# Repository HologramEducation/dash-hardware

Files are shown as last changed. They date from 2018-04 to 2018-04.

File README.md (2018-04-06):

# Hologram Dash Hardware Repository

The Hologram Dash is an Open-Sourced Cellular MCU Developer Board utilizing the [ublox SARA](https://www.u-blox.com/en/product-search/field_product_form/sara-111) family of modems, [ARM Cortex-M0+](https://www.mouser.com/ProductDetail/NXP-Freescale/MKL17Z256VFM4/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), and an [ARM Cortex-M4](https://www.mouser.com/productdetail/nxp-freescale/mk22fn1m0avlh12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). 

Certified by the Open Source Hardware Association - [Certificate US000082](http://certificate.oshwa.org/certification-directory/).

We're excited to see what you'll build with these designs. If you require support for integrating these designs into your project, you can reach out to Hologram Solutions Engineering at sales@hologram.io to learn about Hologram design review services or hear about our engineering design partners.

### Additional Dash Information

 - [Dash Product Page](https://hologram.io/dash/)
 - [Dash Datasheet](https://hologram.io/docs/reference/dash/datasheet/)
 - [Pre v1.2 Dash Repo](https://github.com/hologram-io/hologram-hardware)

### Additional Freescale Documentation

 - [Freescale ARM Cortex-M0+ MKL17Z256VFM4 Datasheet](https://www.mouser.com/ds/2/302/KL17P64M48SF6-1126486.pdf)
 - [Freescale ARM Cortex-M4 MK22FN1M0AVLH12 Datasheet](https://www.mouser.com/ds/2/302/K22P64M120SF5V2-1126240.pdf)

### Additional ublox SARA Documentation

**2G/3G - U200 series**
 - [SARA-U2 System Integration Manual](https://www.u-blox.com/sites/default/files/SARA-G3-U2_SysIntegrManual_%28UBX-13000995%29_0.pdf)
 - [u-blox AT Commands Manual](https://www.u-blox.com/sites/default/files/u-blox-CEL_ATCommands_%28UBX-13002752%29.pdf)
 - [AT Command Examples for u-blox cellular modules](https://www.u-blox.com/sites/default/files/AT-CommandsExamples_AppNote_%28UBX-13001820%29.pdf)
 - [Multiplexer implementation in cellular modules](https://www.u-blox.com/sites/default/files/products/documents/MuxImplementation_ApplicationNote_%28UBX-13001887%29.pdf)
 
**LTE Cat M1/NB1 and EGPRS - R400/N400 series**

 - [SARA-R4 System Integration Manual](https://www.u-blox.com/sites/default/files/SARA-R4_SysIntegrManual_%28UBX-16029218%29.pdf)
 - [SARA-R4 AT Commands Manual](https://www.u-blox.com/sites/default/files/SARA-R4_ATCommands_%28UBX-17003787%29.pdf)

**Power-optimized NB-IoT - N200 series**

 - [SARA-N2 System Integration Manual](https://www.u-blox.com/sites/default/files/SARA-N2_SysIntegrManual_%28UBX-17005143%29.pdf)
 - [SARA-N2 AT Commands](https://www.u-blox.com/sites/default/files/SARA-N2_ATCommands_%28UBX-16014887%29.pdf)

### Additional Hologram Information

 - [BLOG Why We Open Source Hardware](https://hologram.io/open-sourcing-our-hardware/)
 - [Documentation](https://hologram.io/docs/)
 - [Forums](https://community.hologram.io/)

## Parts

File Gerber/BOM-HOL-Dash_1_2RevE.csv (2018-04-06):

Internal PN | LibRef | Quantity | Designator | Description | Footprint | Comment | MFG | MPN
CON-0006 | ANT-A-1JB | 1 | ANT_UFL | Amphenol | UFL | ANT-A-1JB | Amphenol | A-1JB
CON-0010 | BAT_TERM_TOP_ENTRY | 1 | J20 | Battery Connector JST-PH2 Top Entry | JST-PH-2-Top | BAT_TERM_TOP_ENTRY | JST | B2B-PH-SM4-TB(LF)(SN)
CAP-0004 | CAP0.1uF_0402 | 15 | C2, C3, C4, C6, C7, C8, C9, C12, C14, C15, C18, C24, C25, C26, C48 | CAPACITOR, 0.1 uF, 0402 | CAP0402 | 0.1 uF | MURATA | GRM155R61C104KA88D
CAP-0005 | CAP1uF_0402 | 3 | C16, C20, C49 | CAPACITOR, 1uF, 0402 | CAP0402 | 1uF | AVX | 04026D105KAT2A
CAP-0001 | CAP1uF_0603 | 1 | C1 | Capacitor, 1 uF, 0603 | CAP0603 | 1 uF | MURATA | GRM188R71C105KA12D
CAP-0002 | CAP2.2uF_0603 | 4 | C10, C11, C13, C28 | Capacitor, 2.2 uF, 0603 | CAP0603 | 2.2 uF | SAMSUNG | CL10A225MQ8NNNC
CAP-0016 | CAP10nF_0402 | 2 | C27, C39 | CAPACITOR, 10 nF, 0402 | CAP0402 | 10 nF | MURATA | GRM155R71C103KA01D
CAP-0007 | CAP10uF_0603 | 2 | C33, C34 | Capacitor, 10 uF, 0603 | CAP0603 | 10 uF | Murata | GRM188R60J106ME84D
CAP-0011 | CAP15pF_0402 | 1 | C46 | CAPACITOR, 15 pF, 0402 | CAP0402 | 15 pf | AVX/ELCO | 04025A150JAT2A
CAP-0008 | CAP22uF_0603 | 3 | C36, C37, C38 | Capacitor, 22 uF, 0603 | CAP0603 | 22 uF | MURATA | GRM188R60J226MEA0D
CAP-0010 | CAP47pf_0402 | 4 | C41, C42, C44, C45 | CAPACITOR, 47 pF, 0402 | CAP0402 | 47 pF | AVX | 04025A470JAT2A
CAP-0009 | CAP56pF_0402 | 1 | C40 | CAPACITOR, 56 pF, 0402 | CAP0402 | 56 pf | KEMET | C0402C560J5GACTU
CAP-0012 | CAP330uF_1210P | 1 | C47 | Capacitor, 330 uF, 1210, Polarized Tantalum | CAP1210POL | 330uF | AVX | F950J337MBAAQ2
XTL-0001 | CRYSTAL_16MHz | 1 | X1 | Crystal SMD, 16 MHz | CRYSTAL-SMD-2X1.6 | CRYSTAL_16MHz | AVX | CX2016DB16000D0WZRC1
XTL-0003 | CRYSTAL_32.768K_ABS05 | 2 | X2, X3 | 32.768kHz ±20ppm Crystal 12.5pF 90 kOhm -40°C ~ 85°C Surface Mount 2-SMD | CRYSTAL_ABS05 | 32.768 kHz | Abracon | ABS05-32.768KHZ-T
DIO-0004 | DIODE_0402_200mA | 1 | D8 | Schottky Barrier Diode, 200 mA, 30 V, 0402 package | DIODE_0402 | CDBQR0230L | Comchip | CDBQR0230L
DIO-0005 | DIODE_SOD123F_1A | 2 | U3, U4 | Schottky Barrier Diode, 1.5 A, 30 V, 0402 package | SODFL350X99-2N | CDBQR0230L | Toshiba Semiconductor and Storage | CRS08(TE85L,Q,M)
IND-0001 | FerriteBead_220ohm | 4 | L1, L2, L3, L7 | FerriteBead, 220ohm | RES0603 | FerriteBead_220ohm | Murata | BLM18AG121SN1D
IC-0009 | FREESCALE_MKL17Z256VFM4 | 1 | U6 | Microprocessor, Freescale, MKL17Z256VFM4 | QFN50P50 | FREESCALE_MKL17Z256VFM4 | FREESCALE | MKL17Z256VFM4
FUS-0001 | FUSE_0603 | 1 | F6 | Fuse, 3A, 0603 | RES0603 | 3A | Bourns | SF-0603S300-2
IND-0003 | INDUCTOR_1UH_XFL4020-102MEC | 1 | L5 | Inductor, 1 uH, Coilcraft | COILCRAFT_XFL4020 | 1uH | Coilcraft | XFL4020-102MEC
DIO-0002 | LED_0402_VLMW | 2 | D1, D7 | LED, Vishay White 0402 | LED_0402_VISHAY_VLMW | LED_0402_VLMW | VISHAY | VLMW1500-GS08
DIO-0006 | LED_RGB_1mm_sq | 1 | D2 | LED, Tri-color, RGB, 1mm sq | LED-RGB-1X1 | LED_RGB_1mm_sq | Rohm | SMLP34RGB2W3
IC-0003 | MAX1704X | 1 | U19 | MAX17043/MAX17044: Battery Fuel Guage (43 is 1cell, 44 is 2cell) | TDFN-8 | MAX1704X | Maxim | MAX17043G+U
IC-0012 | MICROCHIP_73871 | 1 | U1 | Stand-alone Load Sharing and LiPo Battery Charge management controller | QFN50P400X400X80_20_pin | MICROCHIP_73871 | MICROCHIP | MCP73871-2CCI/ML
IC-0008 | MK22FN1M0VLH12 | 1 | U5 | ARM® Cortex®-M4 Kinetis K20 Microcontroller IC 32-Bit 120MHz 1MB (1M x 8) FLASH 64-LQFP (10x10) | LQFP-64N | MK22FN1M0VLH12 | Freescale | MK22FN1M0AVLH12
IC-0002 | NCP177-D | 1 | U10 | IC Regulator, LDO 3.3V 0.5A, 4XDFN | XDFN-4 |  | On Semi | NCP177AMX330TCG
DIO-0009 | PESD_14V | 7 | D3, D4, D5, D6, D9, D10, D11 | DIODE,ZENER VOLTAGE SUPPRESSOR,+/-14V | PESD_0402 |  | Littlefuse | PESD0402-140
CON-0011 | PINHD-1X18 | 2 | JLEFT, JRIGHT | Header, Male, 1x18, 0.1",1X18" | 22-28-4180 | MOLEX | 22-28-4180
RES-0011 | RES0R_0402 | 1 | R66 | Resistor, 0 ohm, 0402 | RES0402 | 0 | PANASONIC | ERJ-2GE0R00X
RES-0002 | RES1K_0402 | 1 | R45 | Resistor, 1k, 0402 case, 1% | RES0402 | 1k | YAEGO | RC0402JR-071KL
RES-0014 | RES1M_0402 | 1 | R13 | Resistor, 1M ohm, 0402 case, 1% | RES0402 | 1M | YAEGO | RC0402FR-071ML
RES-0015 | RES2K_0402 | 1 | R8 | Resistor, 2K ohm, 0402 case | RES0402 | 2k | YAEGO | RC0402FR-072KL
RES-0008 | RES10K_0402 | 8 | R24, R35, R36, R37, R38, R40, R47, R2000 | Resistor, 10k ohm, 0402 | RES0402 | 10K | YAEGO | RC0402JR-0710KL
RES-0016 | RES22R_0402 | 2 | R1, R2 | Resistor, 22 ohm, 0402 case, 1% | RES0402 | 22 | YAEGO | RC0402FR-0722RL
RES-0017 | RES62K_0402_1 | 1 | R7 | Resistor, 62K ohm, 0402 case | RES0402 | 62k | YAEGO | RC0402FR-0762KL
RES-0018 | RES75R_0402 | 2 | R26, R65 | Resistor, 75 ohm, 0402, 1% | RES0402 | 75 | YAEGO | RC0402FR-0775RL
RES-0003 | RES100K_0402 | 1 | R51 | Resistor, 100k ohm, 0402 | RES0402 | 100K | PANASONIC | ERJ-2GEJ104X
RES-0019 | RES120R_0402 | 1 | R21 | Resistor, 120 ohm, 0402 case, 1% | RES0402 | 120 | PANASONIC | ERJ-2GEJ121X
RES-0004 | RES150K_0402 | 1 | R12 | Res, 150k ohm, 0402 case, 1% | RES0402 | 150k | YAEGO | RC0402FR-07150KL
RES-0020 | RES160R_0402 | 1 | R22 | Resistor, 160 ohm, 0402 case, 1% | RES0402 | 160 | PANASONIC | ERJ-2GEJ161X
RES-0006 | RES470R_0402 | 2 | R19, R20 | Resistor, 470 ohm, 0402 case, 1% | RES0402 | 470 | PANASONIC | ERJ-2GEJ471X
IC-0007 | SARA-U2XX | 1 | U16 | Module, uBlox, SARA-U2xx | SARA | SARA-U2XX | U-BLOX | SARA-U260-00S
CON-0007 | SIM_CARD_NANO | 1 | SIM1 | Connector, SIM Card,Nano | SIM_CARD_NANO | SIM_CARD_NANO | GLOBAL CONNECTOR TECHNOLOGY | SIM8050-6-0-14-01-A
SWI-0001 | SWITCH_PTS810 | 2 | SW1, SW2 | Switch, C&K, PTS810 | SWITCH_PTS810 | SWITCH_PTS810 | C&K Components | PTS810 SJM 250 SMTR LFS
IC-0017 | TPS22945 | 1 | U9 | IC, Current-limited Load Switch, Active High | SC70-5 |  | Texas Instruments | TPS22945DCKR
IC-0013 | TPS63020 | 1 | U2 | Regulator, Boost Buck, Adjustable, 3A | QFN-14-POWERPAD3X4DSJ | TPS63020 | TI | TPS63020DSJ
CON-0009 | USB_MICRO_B_FCI_10118193 | 1 | J1 | Connector, Micro USB B, FCI | USB_MICRO_FCI_10118193 | Micro USB B FCI 10118193 | Amphenol FCI | 10118193-0001LF
IC-0011 | VOLTAGE_TRANSLATOR_4_BIT | 1 | U8 | IC, Voltage Translator, 4-bit | UQFN_16 | VOLTAGE_TRANSLATOR_4_BIT | TI | SN74AVC4T774RSVR

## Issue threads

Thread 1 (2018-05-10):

Add instructions for initial programming of Dash

rbalik, 2018-05-10:
The first time you program a Dash after manufacturing, it can't be done via USB and must use the SWD pins. We have a procedure to do this via openocd on the Raspberry Pi and should document it for open source users.

1tron1, 2018-06-05:
@rbalik is there any update on this? We're interested in using the Ublox module but adding BT and Wifi chipset on board and so any help on this front would help us get our new boards up and going with Holo quicker.

rbalik, 2018-06-08:
Sorry that I haven't had a chance to get this all written up yet. I might be able to put something together over the next few days.

1tron1, 2018-06-12:
@rbalik thanks!

rbalik, 2018-06-22:
So for now I'm going to drop some notes in here so people can get started and then can work on a more formal doc over the coming weeks.

So the way initial programming works is you have to program the user and system micros by plugging in certain pins into the raspberry pi and using openocd to write to the flash on each micro.

Here are the pins to plug in (note this only works with the Dash 1.2):

Dash -> RPi
R18 (SYS SWD CLK) -> BCM 25 (22)
L18 (SYS SWD IO) -> BCM 24 (18)
R10 (SYS RESET) -> BCM 18 (12)
L17 (USR SWD CLK)) -> BCM 21 (40)
L16 (USR SWD IO) -> BCM 20 (38)
L15 (USR RESET) -> BCM 16 (36)
R2 (GND) -> GND (6)
These next two are optional, but we use them in the factory to easily run some tests and verify installation is ok. You can do this over USB instead if you want. (You might also need to reconfigure something on the pi for these pins to show up as a serial port)
L08 (UART TX) -> BCM 15 (10)
L06 (UART RX) -> BCM 14 (8)

You'll need to compile openocd from source on hte Pi because the version in apt doesn't support everything needed. Fortunately there are instructions for this here: https://movr0.com/2016/09/02/use-raspberry-pi-23-as-a-jtagswd-adapter/

Openocd config files are attached here:
[openocd-dashconfig.tar.gz](https://github.com/HologramEducation/dash-hardware/files/2125983/openocd-dashconfig.tar.gz)

Firmware binaries are here
[dashfirmware.tar.gz](https://github.com/HologramEducation/dash-hardware/files/2125978/dashfirmware.tar.gz)

The commands you'll run are:
`openocd -f system0.cfg -f system_boot.cfg -c program dash_system_module_firmware_0.10.1.bin 0x6000 verify reset exit`

`openocd -f user0.cfg -f user_boot.cfg -c program repl_0.11.0.bin 0x8000 verify reset exit`

Let me know if you run into any trouble here. I'll try to put this into a better formatted doc soon.

labiancoCgi, 2019-04-03:
Hi @rbalik, I am trying to program the Dash MCUs by using the JLINK J-flash lite. Is there any reason why this would not work?

If not, do you know the initial address at which to program the binaries.

Thanks!

rbalik, 2019-04-23:
Been a while since I looked at this but it seems like it should work if you're using the right pins. I think the addresses in those openocd commands are the starting addresses

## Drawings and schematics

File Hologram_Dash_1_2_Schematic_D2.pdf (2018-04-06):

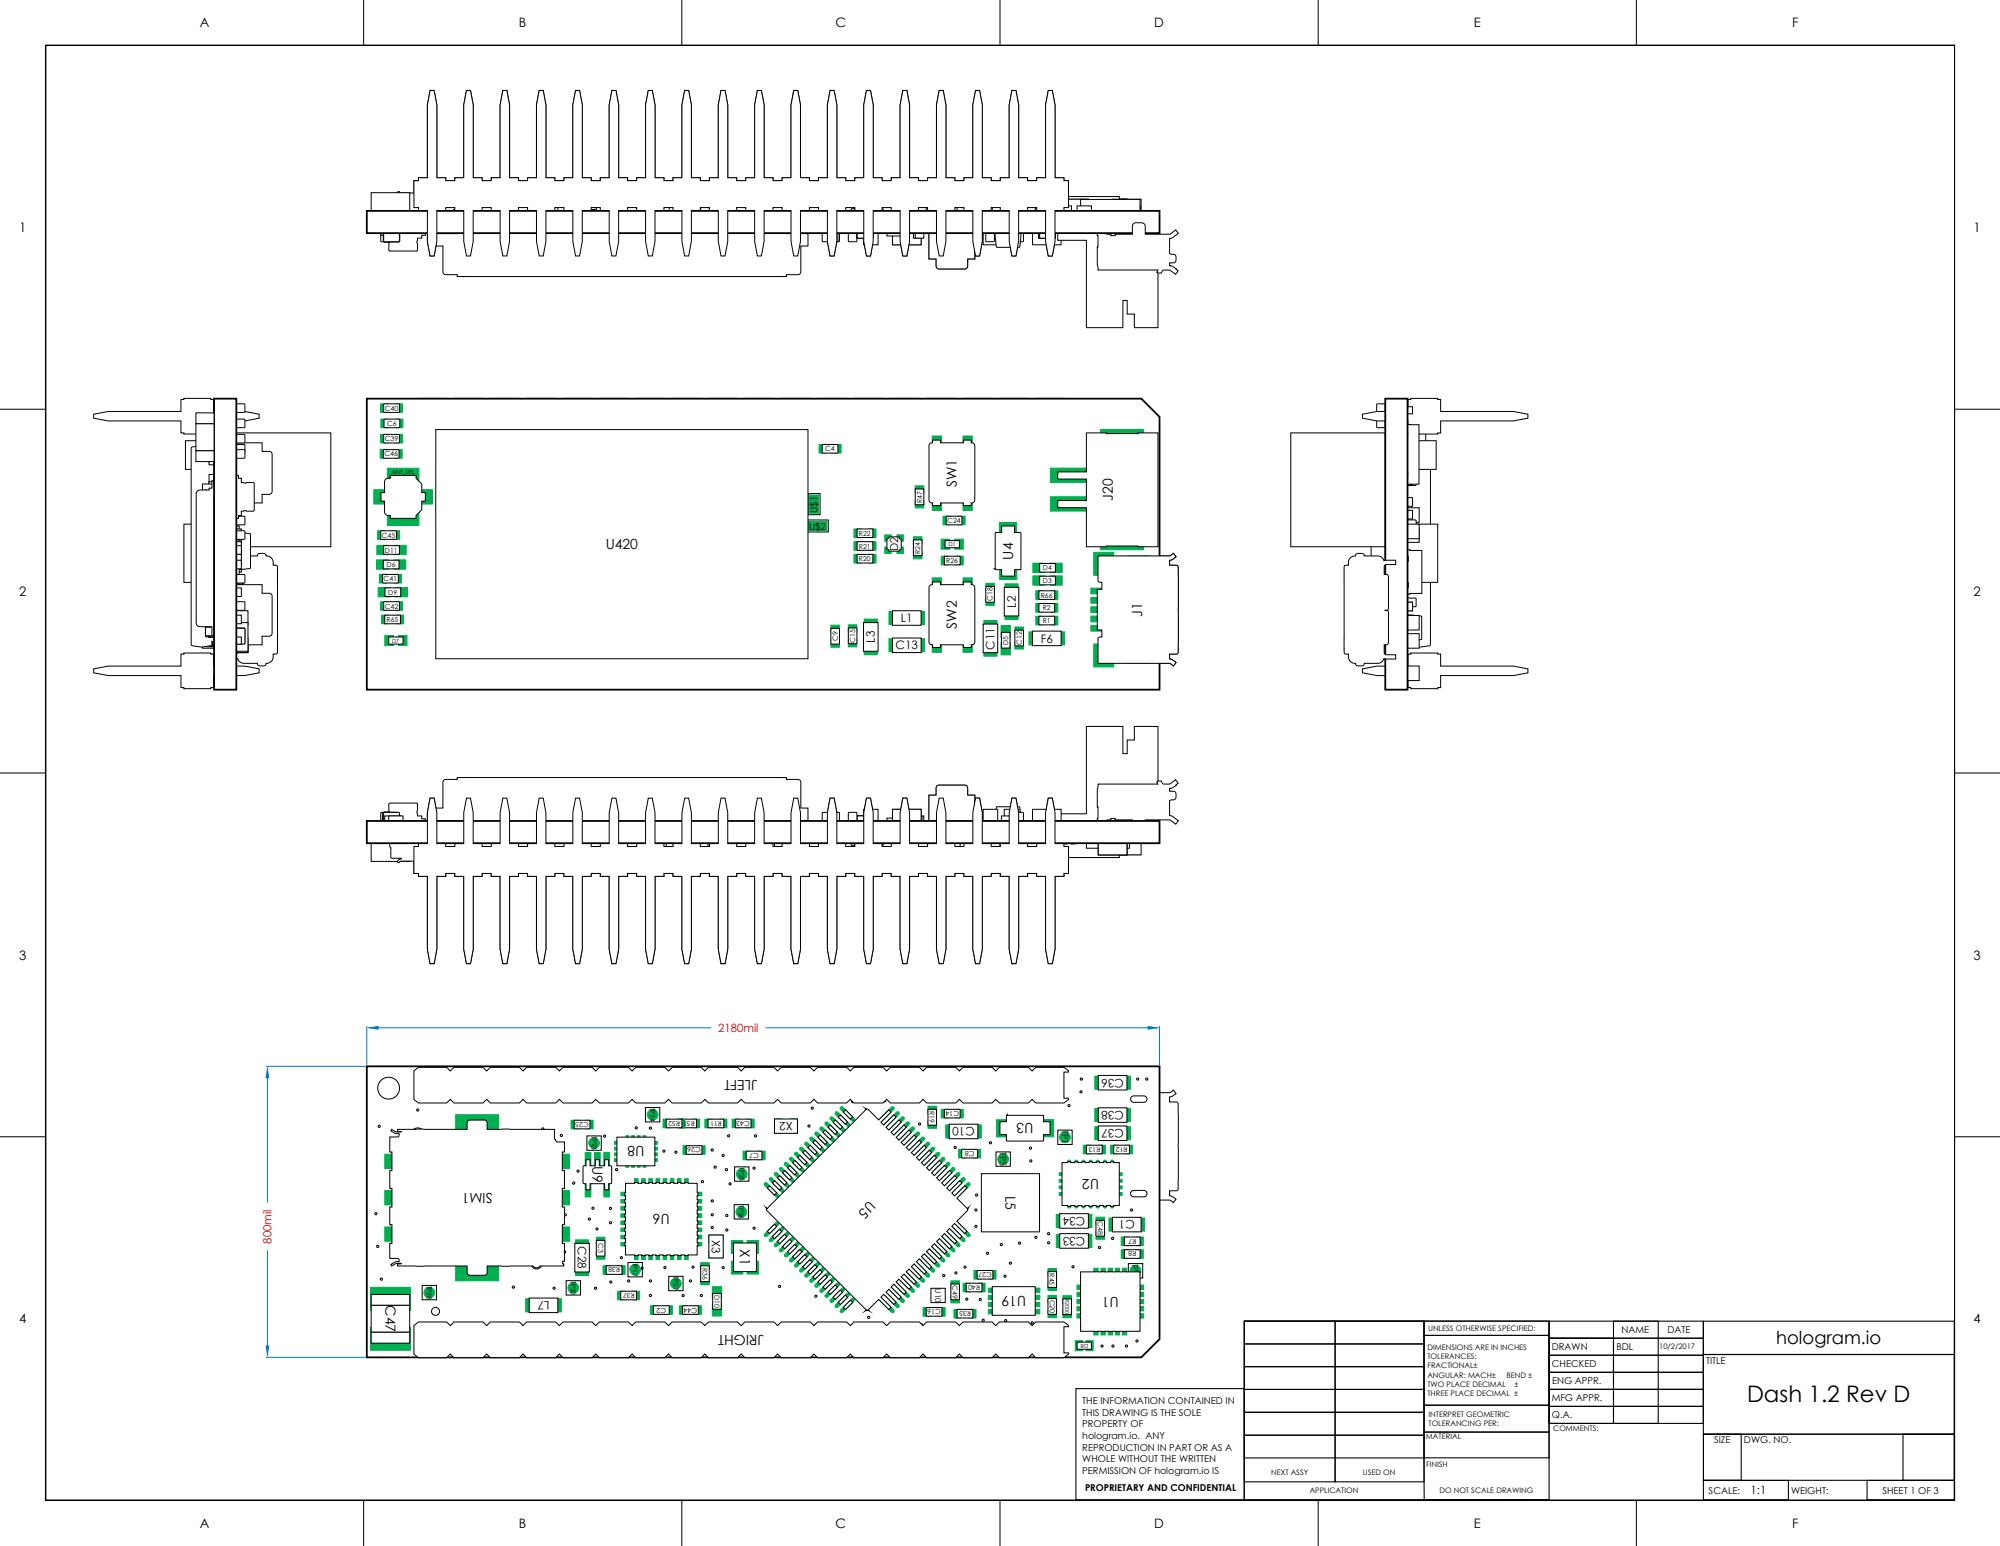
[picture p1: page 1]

DIMENSIONS ARE IN INCHES
TOLERANCES:
FRACTIONAL±
ANGULAR: MACH± BEND ±
TWO PLACE DECIMAL ±
THREE PLACE DECIMAL ±

THE INFORMATION CONTAINED IN
THIS DRAWING IS THE SOLE
PROPERTY OF
hologram.io. ANY
REPRODUCTION IN PART OR AS A
WHOLE WITHOUT THE WRITTEN
PERMISSION OF hologram.io IS
PROPRIETARY AND CONFIDENTIAL

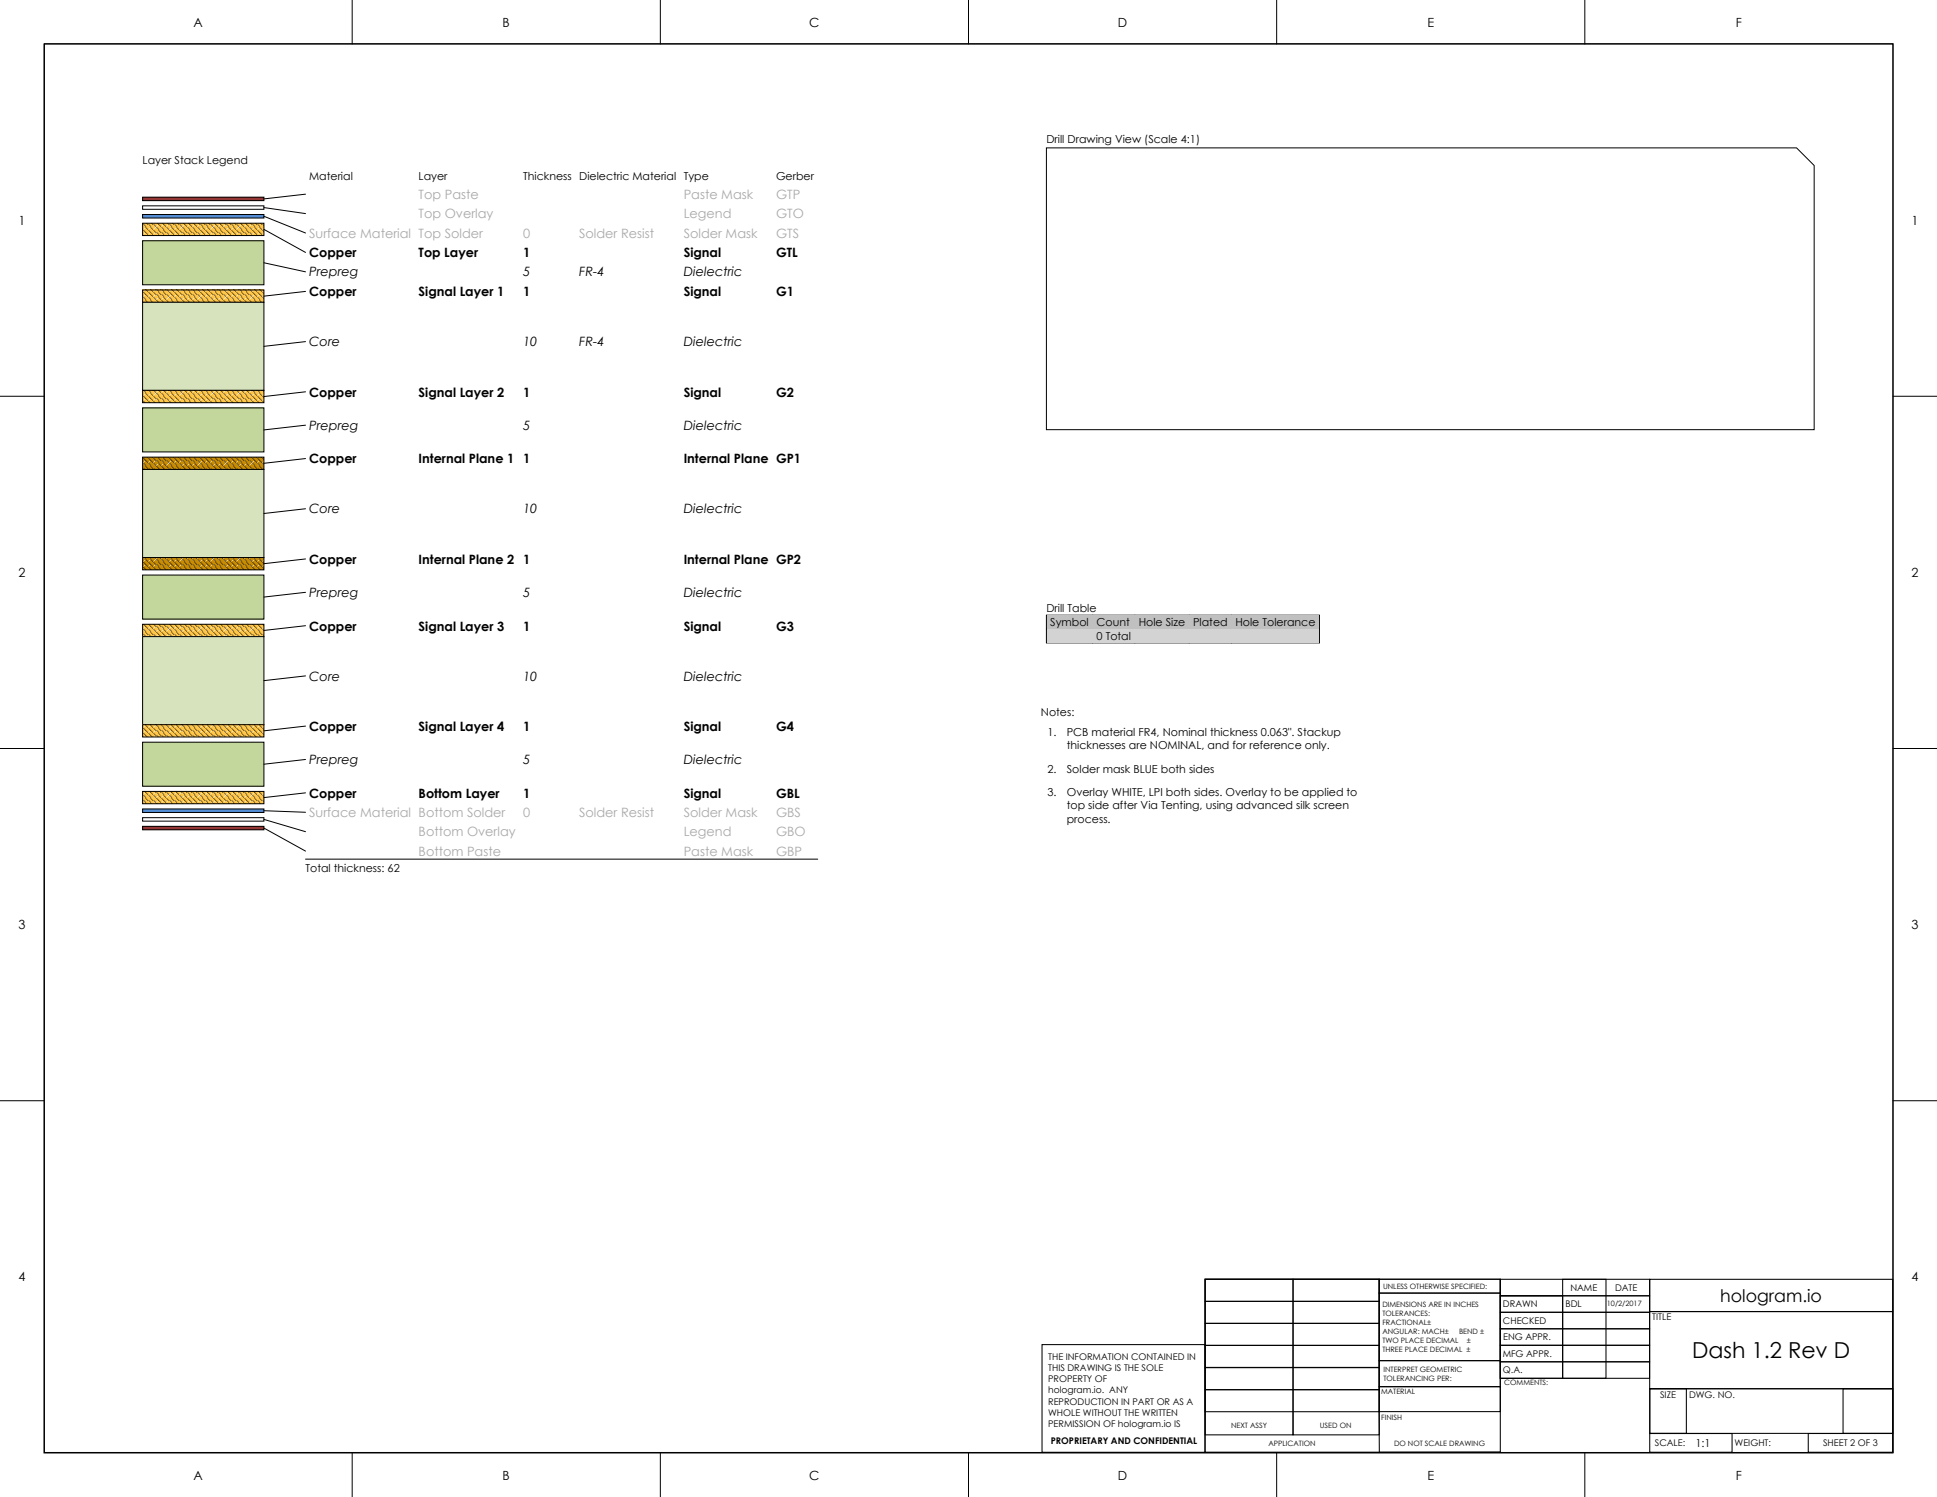
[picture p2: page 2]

Drill Drawing View (Scale 4:1)

Symbol | Count | Hole Size | Plated | Hole Tolerance

0 Total

Notes:
PCB material FR4, Nominal thickness 0.063". Stackup
thicknesses are NOMINAL, and for reference only.
2. Solder mask BLUE both sides
Overlay WHITE, LPI both sides. Overlay to be applied to
top side after Via Tenting, using advanced silk screen
process.

UNLESS OTHERWISE SPECIFIED: | | NAME | DATE 10/2/2017 | hologram.io
DIMENSIONS ARE IN INCHES TOLERANCES: FRACTIONAL± ANGULAR: MACH± BEND ± TWO PLACE DECIMAL ± THREE PLACE DECIMAL ± | DRAWN | BDL

CHECKED | | | TITLE Dash 1.2 Rev D
ENG APPR.

THE INFORMATION CONTAINED IN THIS DRAWING IS THE SOLE | | | MFG APPR.

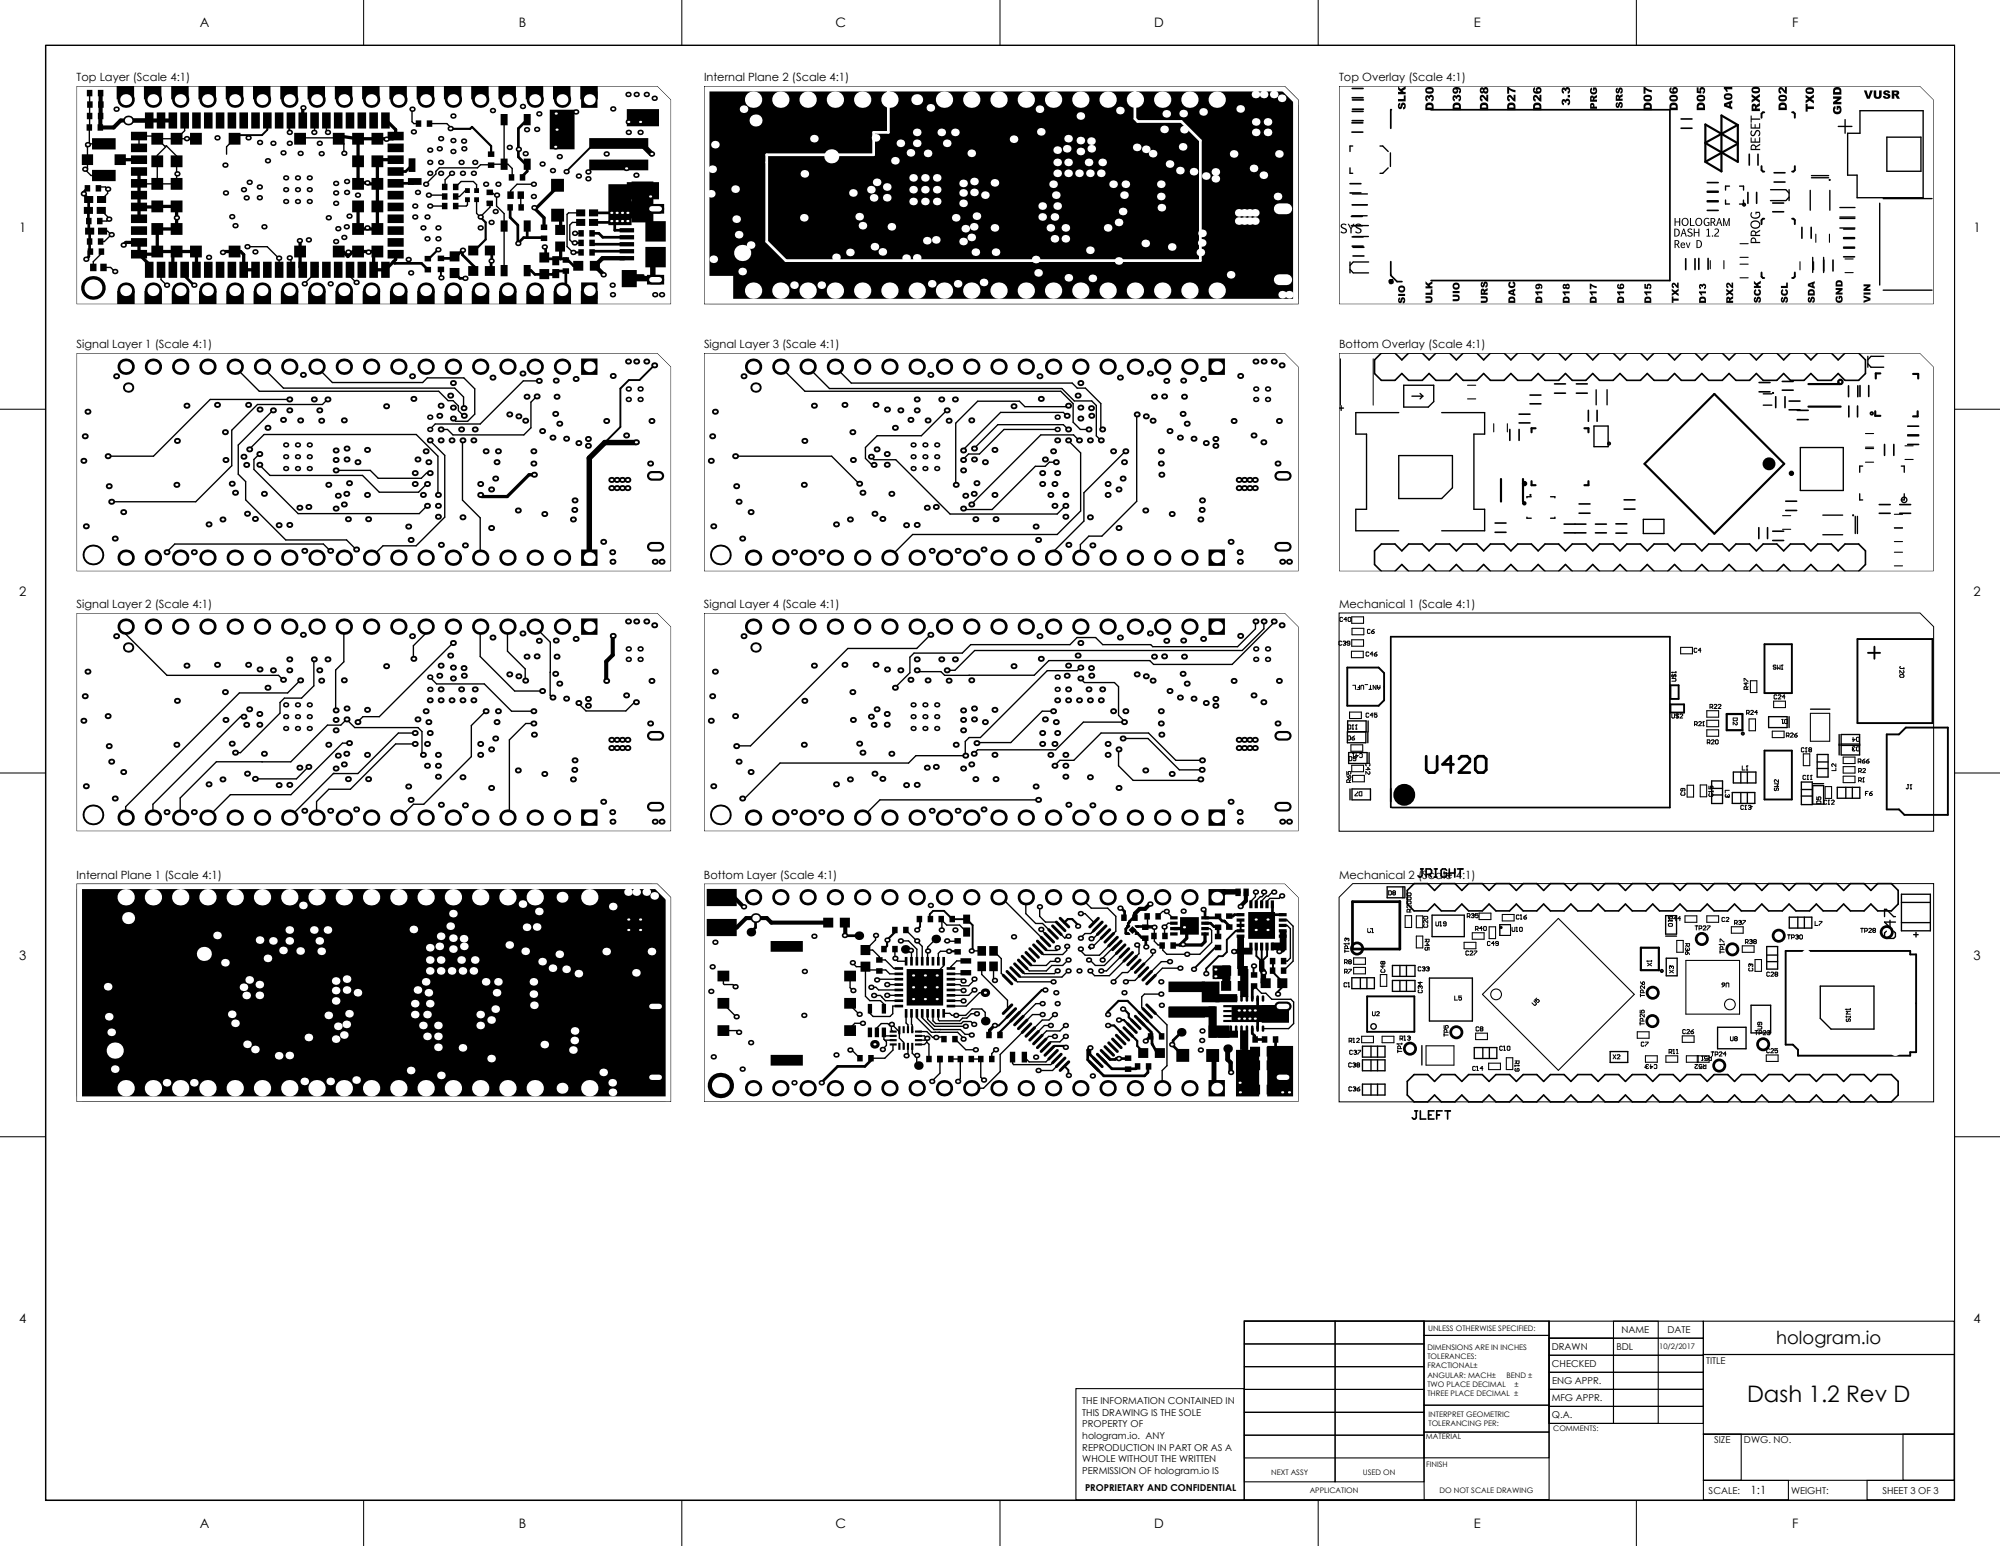
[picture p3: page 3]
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

CHECKED | | | TITLE Dash 1.2 Rev D
ENG APPR.

THE INFORMATION CONTAINED IN THIS DRAWING IS THE SOLE | | | MFG APPR.

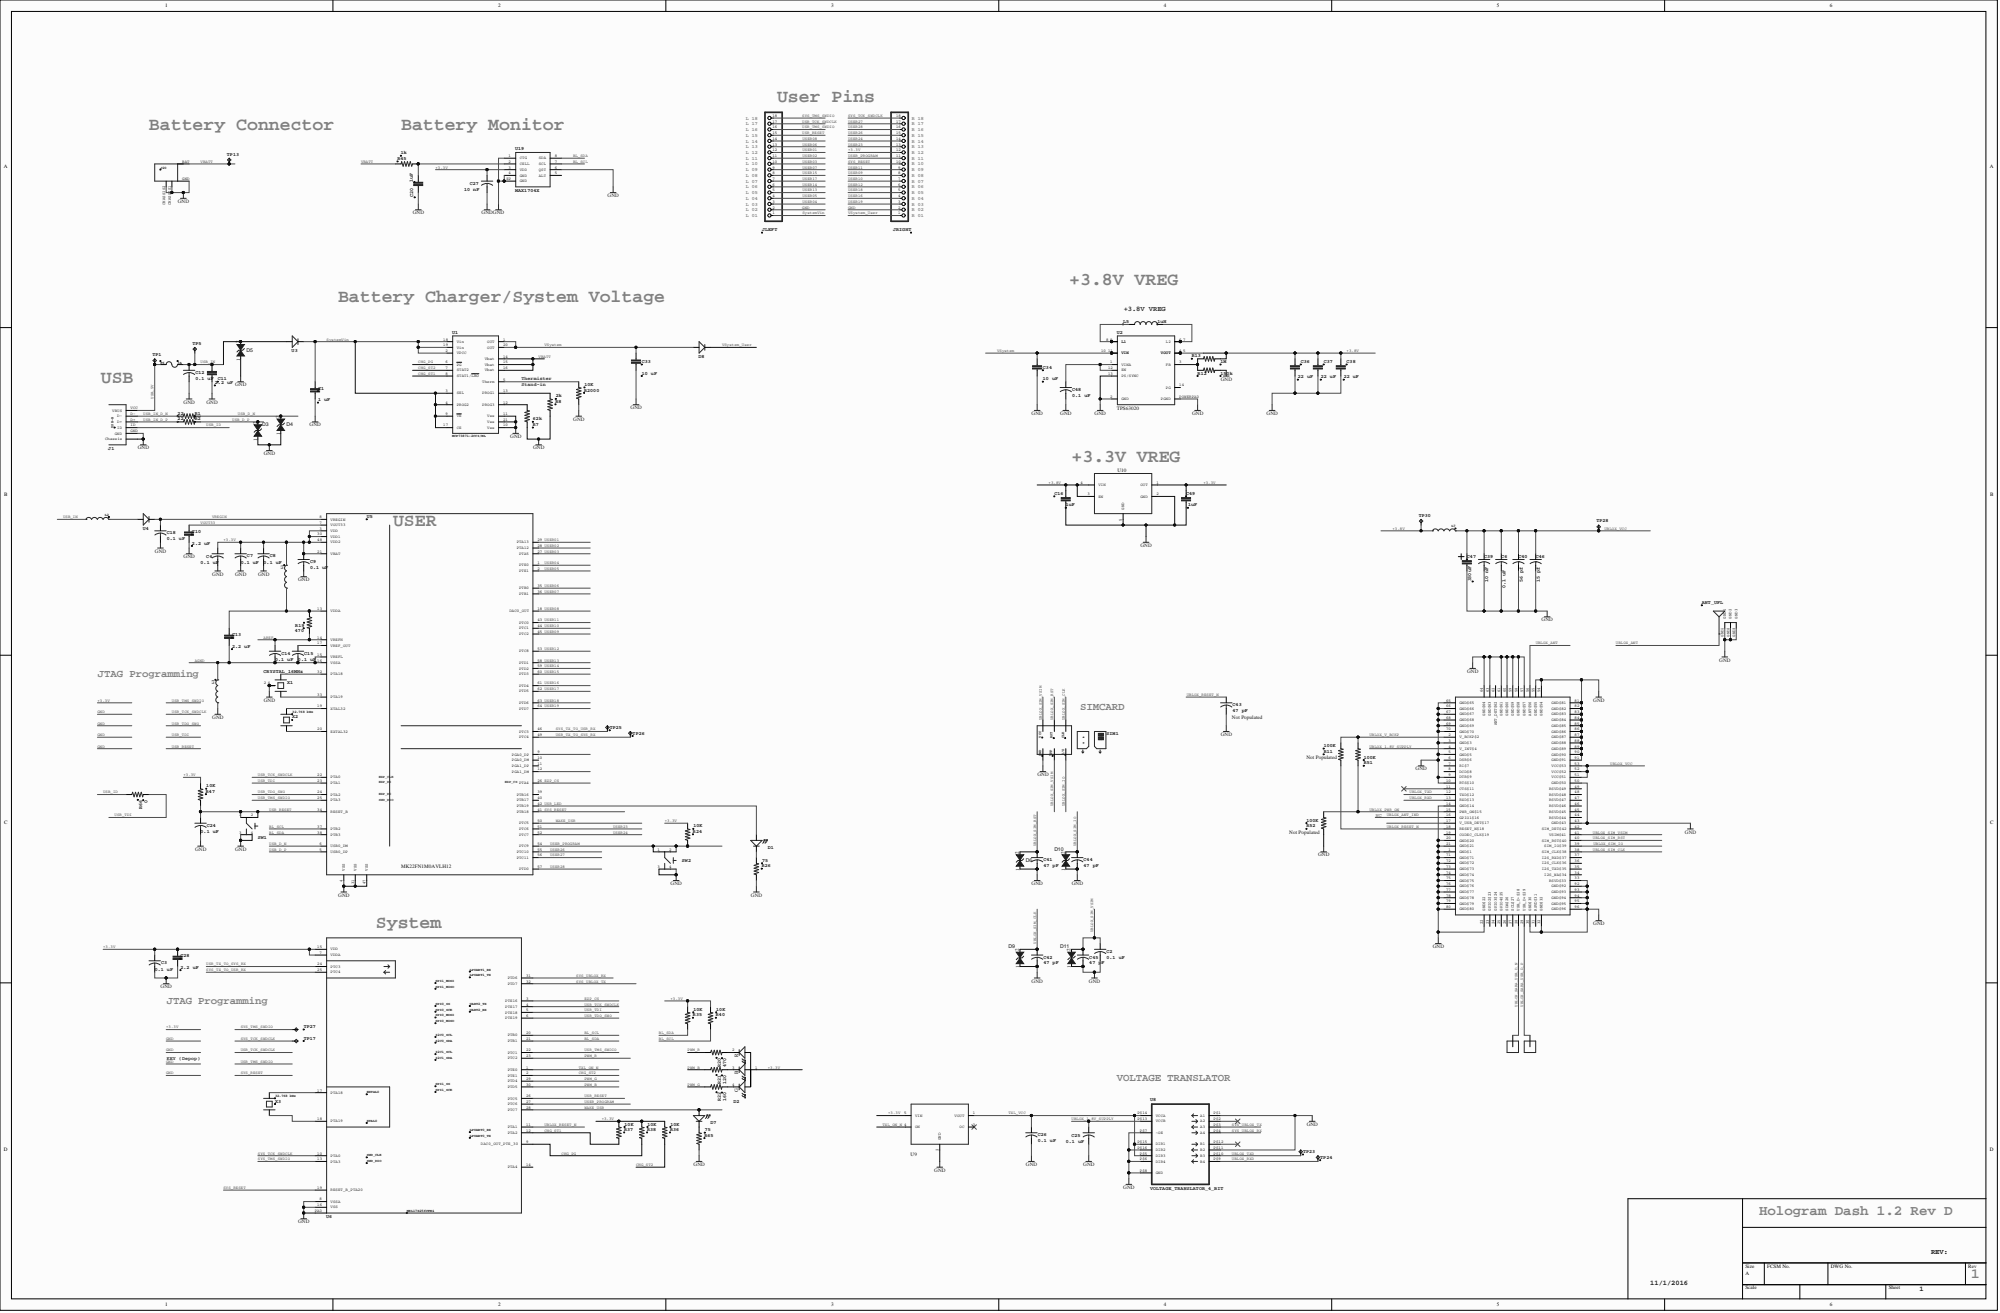
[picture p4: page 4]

Battery Charger/System Voltage

PROG2 4

VOUT33 | VOUT33 7

VDD 3
VDD1 30

VREF_OUT 17

VSSA 16

GND$57 57 GND$58 58 GND$59 59 GND$60 60 GND$61 61

DSR$6 6

UBLOX_TXD UBLOX_RXD | | DCD$8 8

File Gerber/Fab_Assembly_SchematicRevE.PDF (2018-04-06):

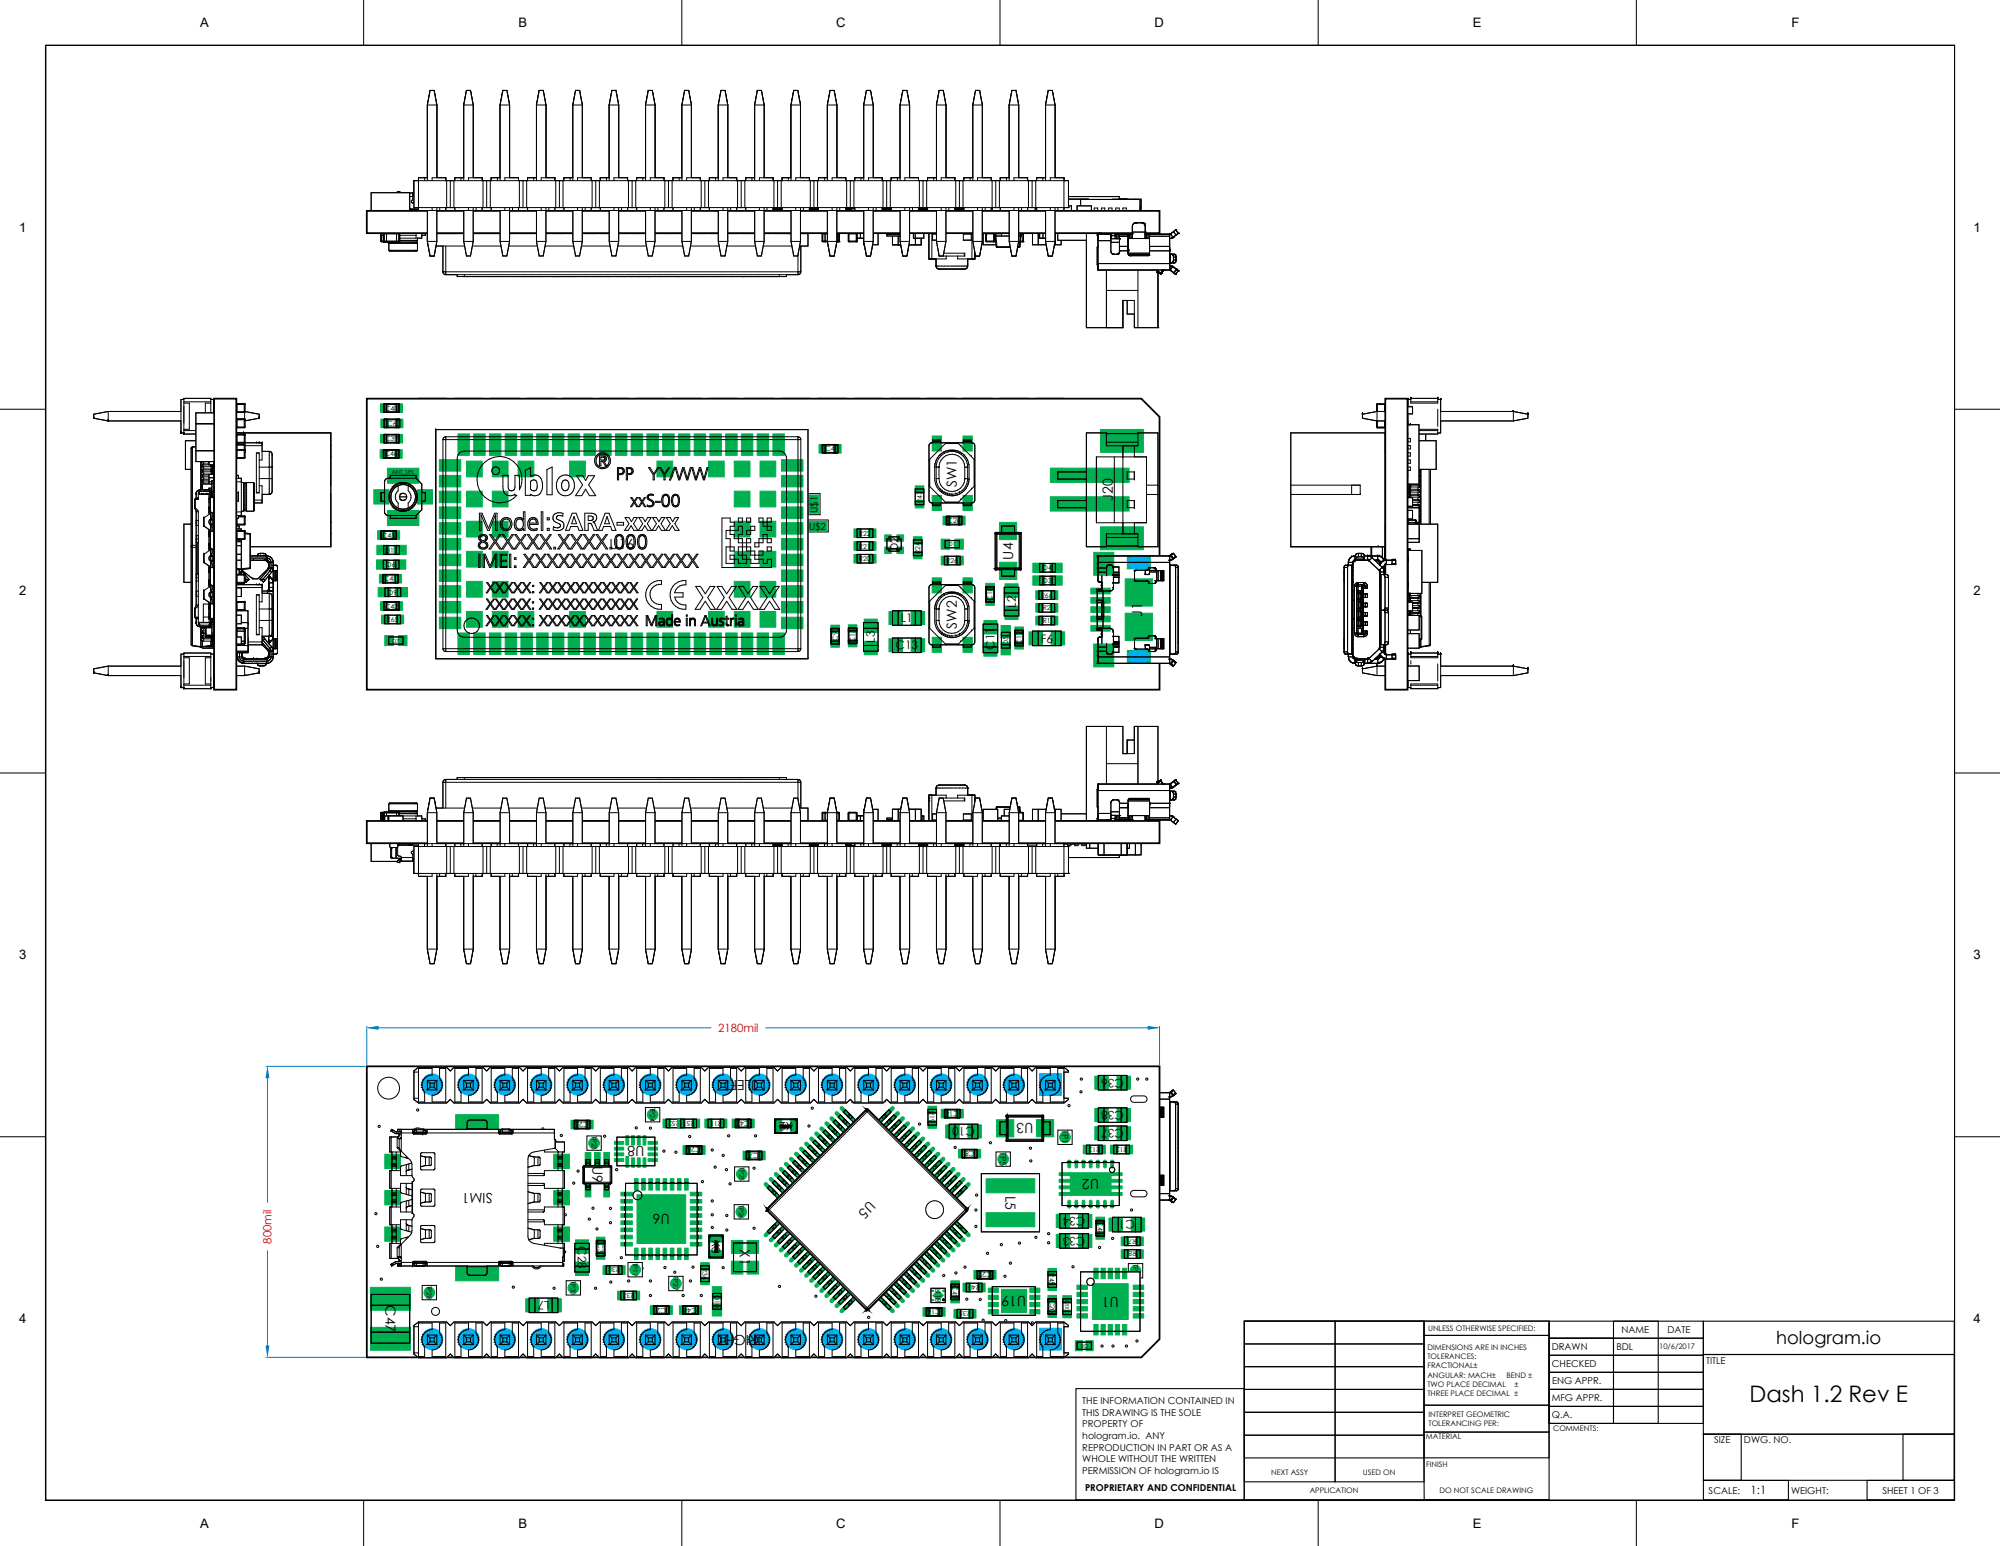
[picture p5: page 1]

DIMENSIONS ARE IN INCHES
TOLERANCES:
FRACTIONAL±
ANGULAR: MACH± BEND ±
TWO PLACE DECIMAL ±
THREE PLACE DECIMAL ±

THE INFORMATION CONTAINED IN
THIS DRAWING IS THE SOLE
PROPERTY OF
hologram.io. ANY
REPRODUCTION IN PART OR AS A
WHOLE WITHOUT THE WRITTEN
PERMISSION OF hologram.io IS
PROPRIETARY AND CONFIDENTIAL

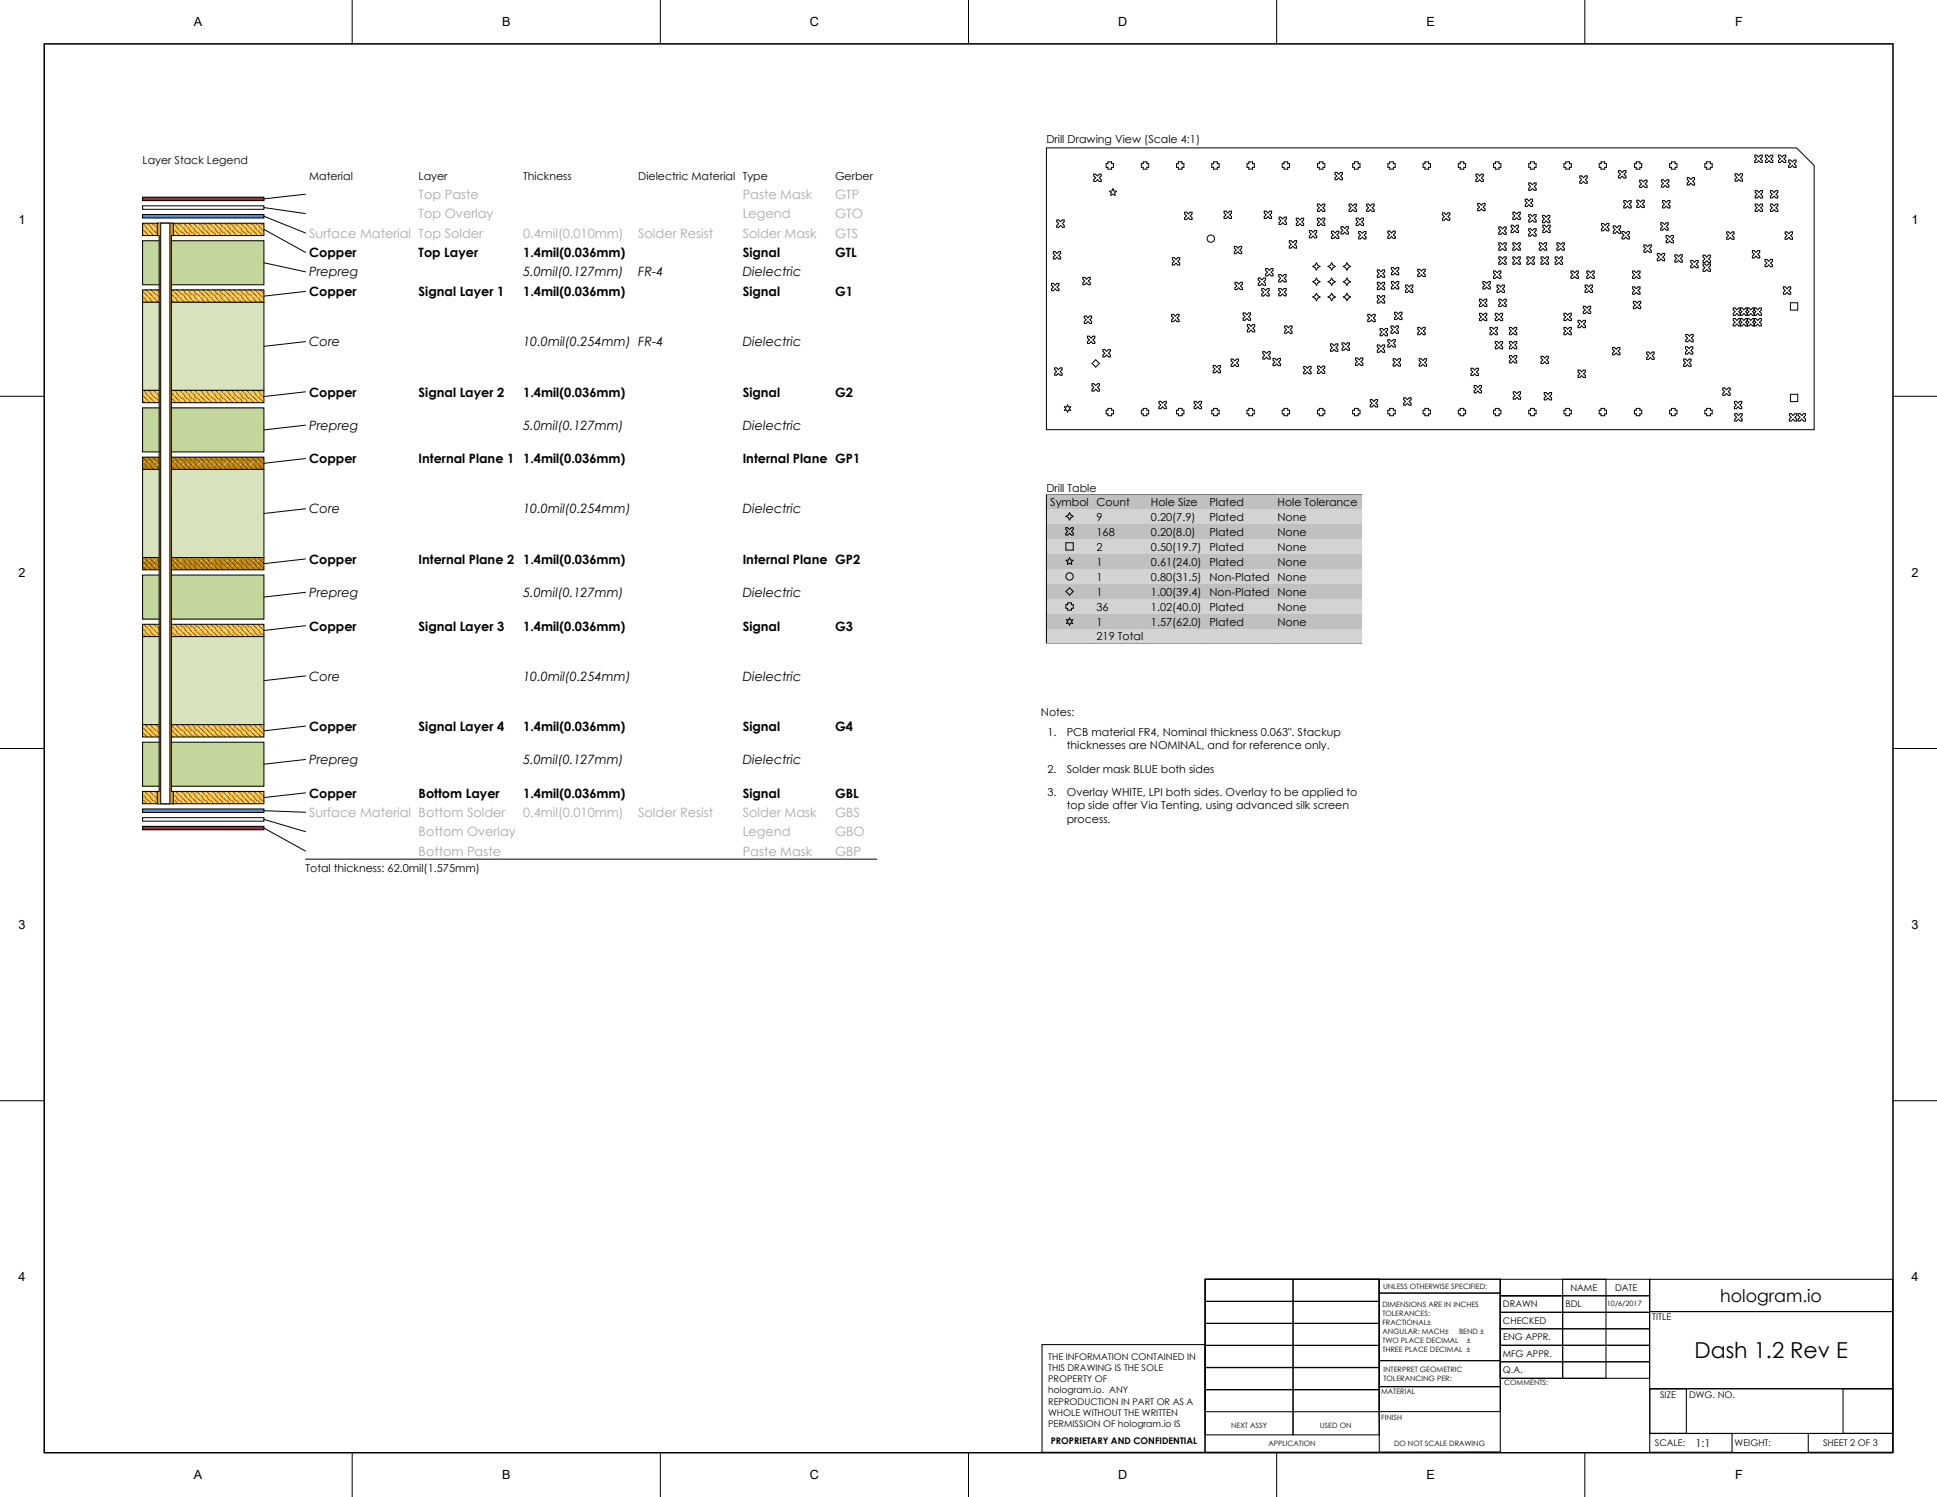
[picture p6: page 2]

Drill Drawing View (Scale 4:1)

Symbol | Count | Hole Size | Plated | Hole Tolerance

9 | 0.20(7.9) | Plated | None
168 | 0.20(8.0) | Plated | None
2 | 0.50(19.7) | Plated | None
1 | 0.61(24.0) | Plated | None
1 | 0.80(31.5) | Non-Plated | None
1 | 1.00(39.4) | Non-Plated | None
36 | 1.02(40.0) | Plated | None
1 | 1.57(62.0) | Plated | None
219 Total

Notes:
PCB material FR4, Nominal thickness 0.063". Stackup
thicknesses are NOMINAL, and for reference only.
2. Solder mask BLUE both sides
Overlay WHITE, LPI both sides. Overlay to be applied to
top side after Via Tenting, using advanced silk screen
process.

UNLESS OTHERWISE SPECIFIED: | | NAME | DATE 10/6/2017 | hologram.io
DIMENSIONS ARE IN INCHES TOLERANCES: FRACTIONAL± ANGULAR: MACH± BEND ± TWO PLACE DECIMAL ± THREE PLACE DECIMAL ± | DRAWN | BDL

CHECKED | | | TITLE Dash 1.2 Rev E
ENG APPR.

THE INFORMATION CONTAINED IN THIS DRAWING IS THE SOLE | | | MFG APPR.

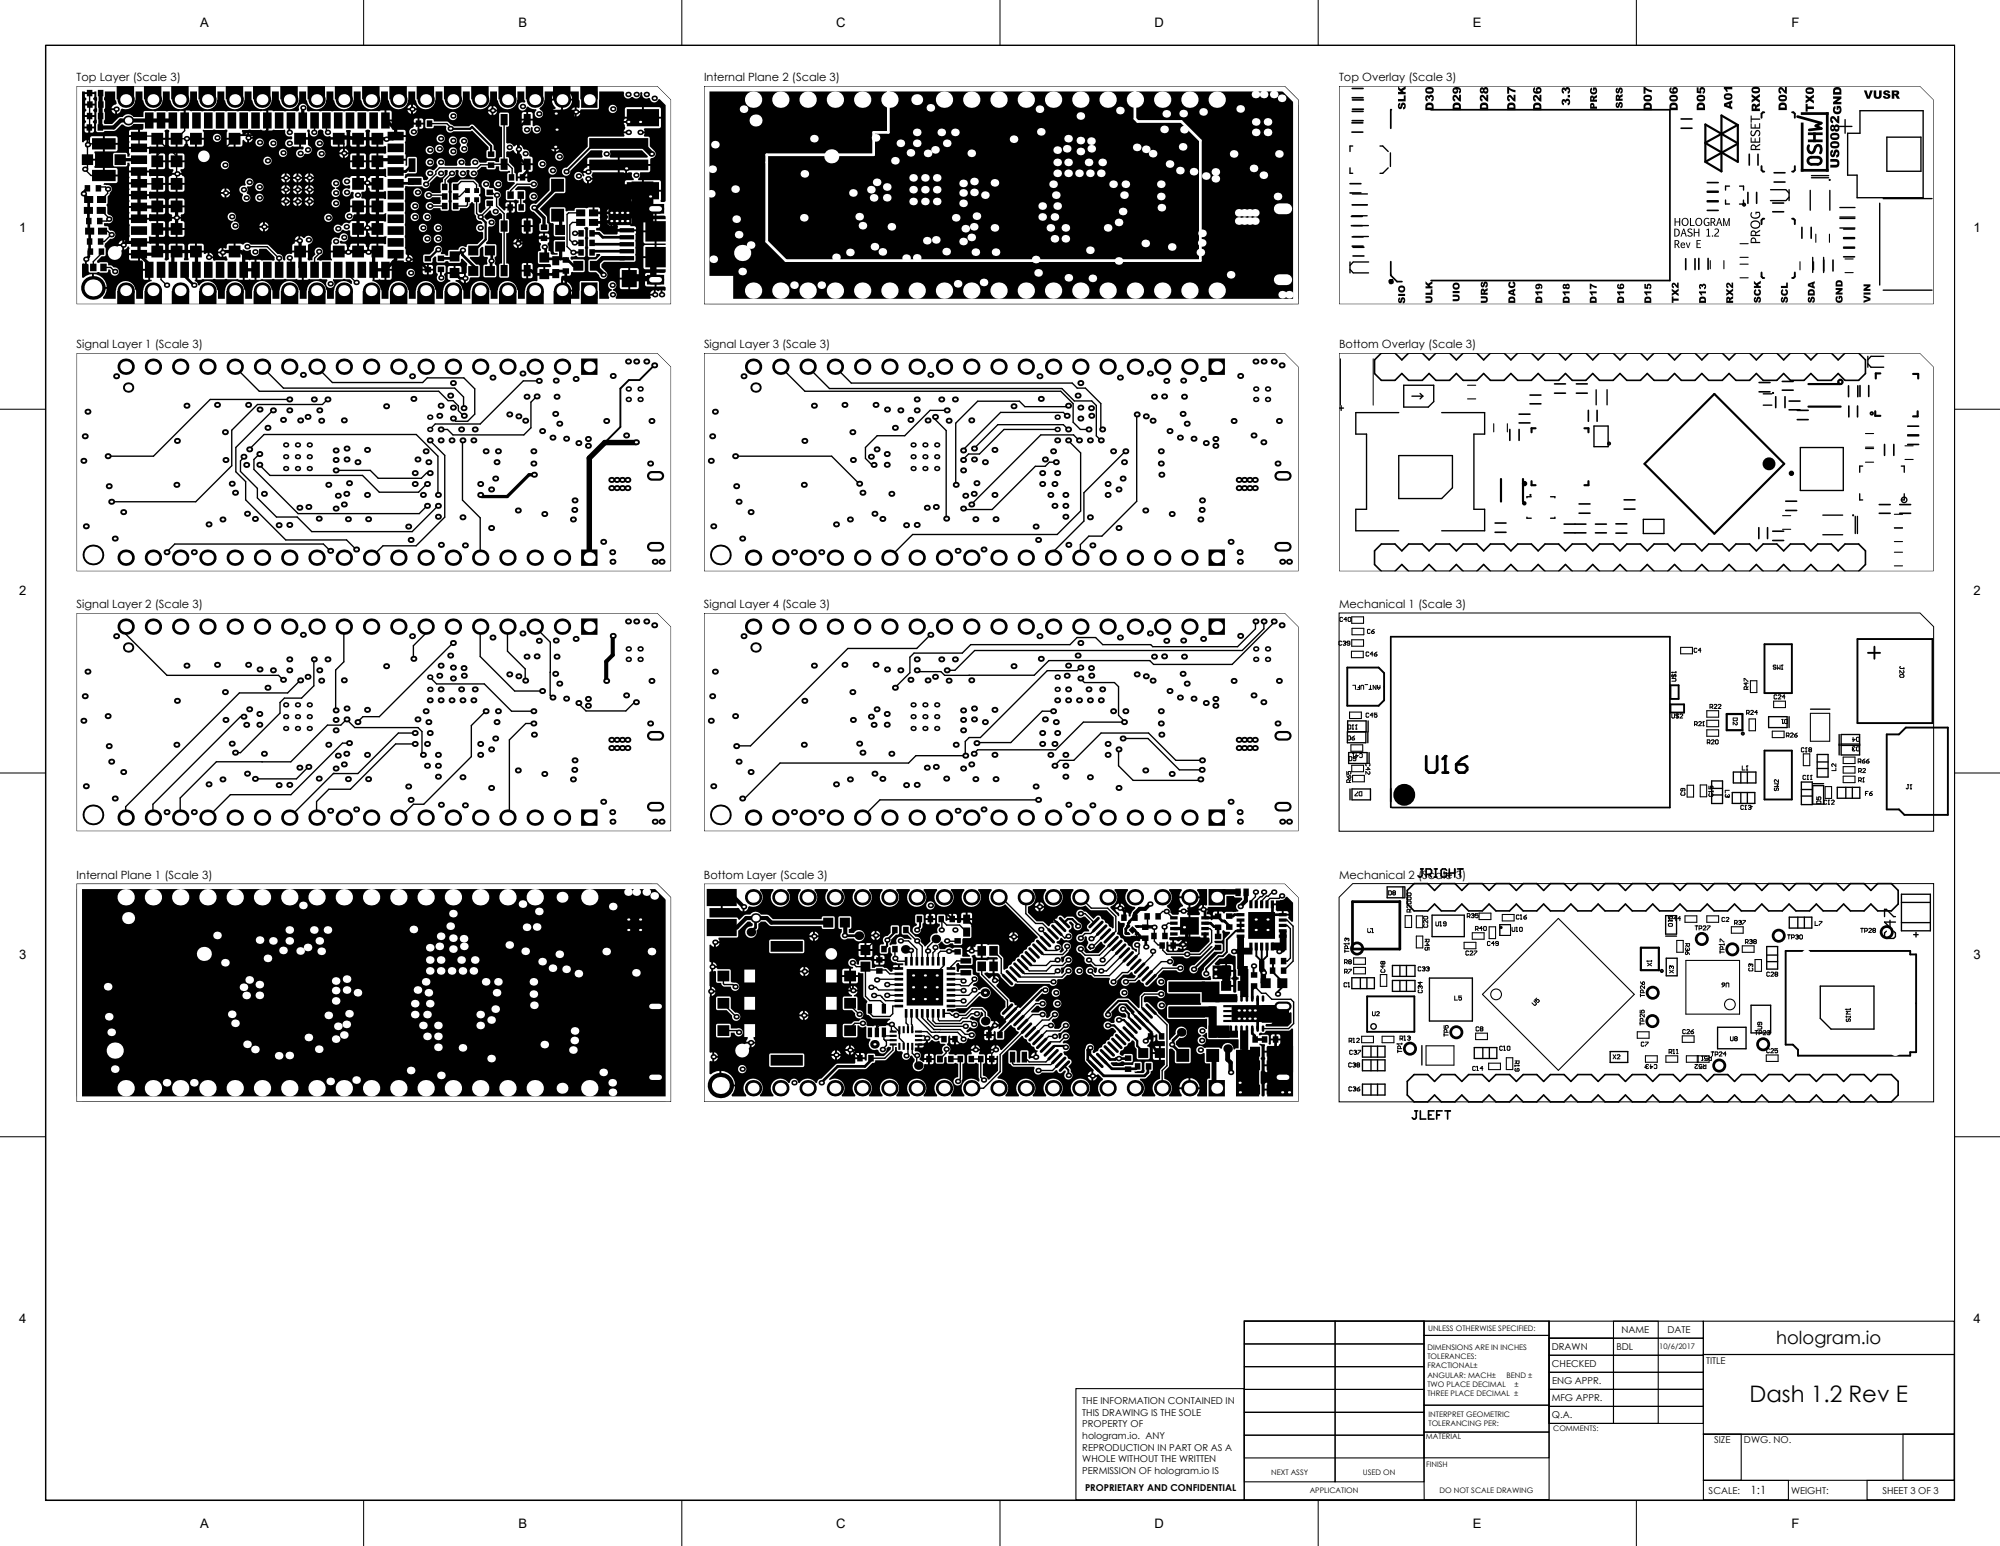
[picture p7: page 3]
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

CHECKED | | | TITLE Dash 1.2 Rev E
ENG APPR.

THE INFORMATION CONTAINED IN THIS DRAWING IS THE SOLE | | | MFG APPR.

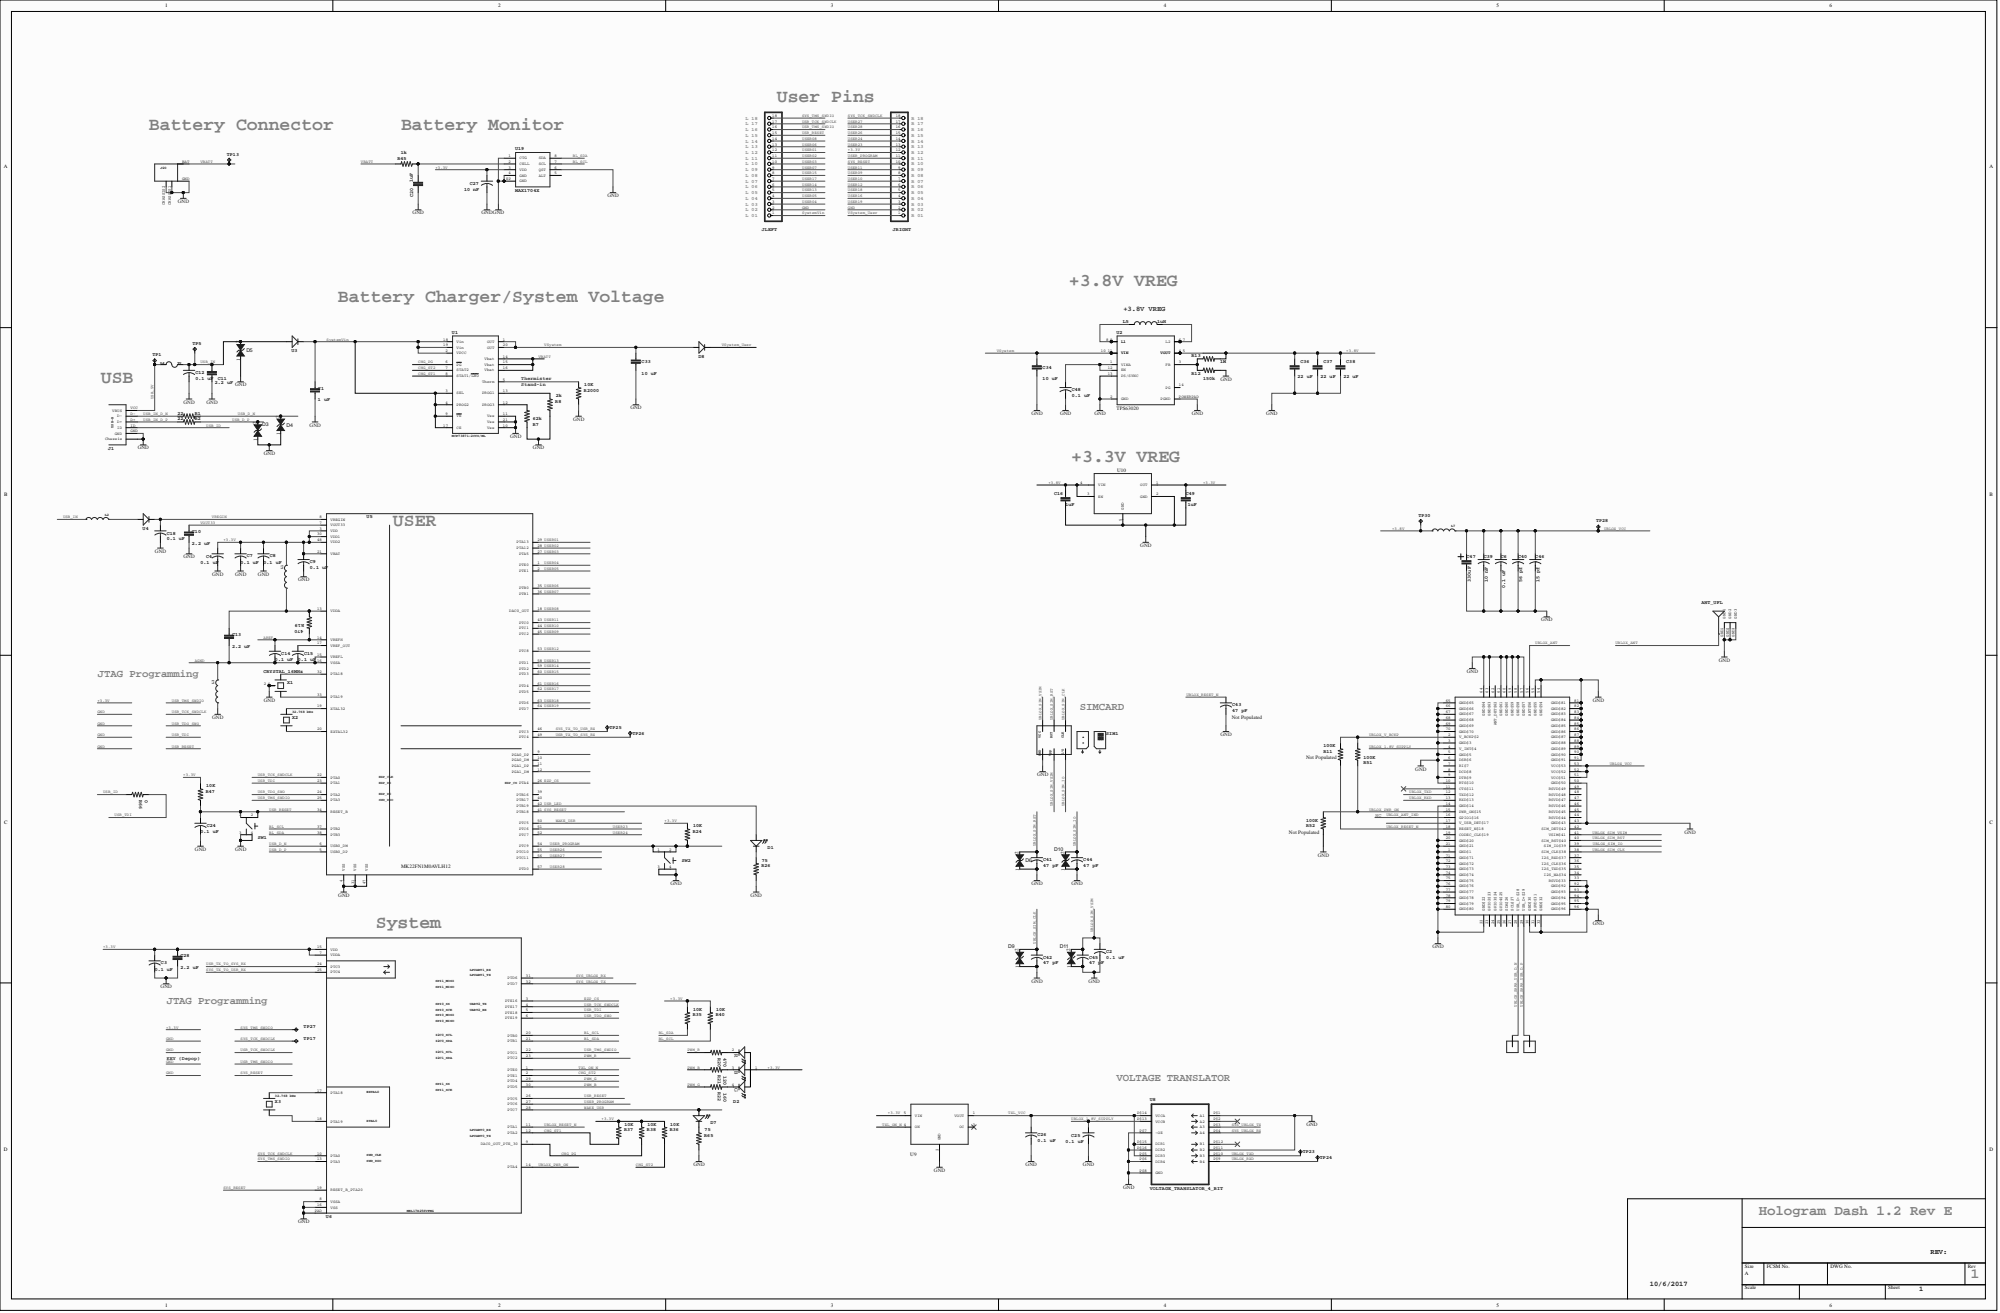
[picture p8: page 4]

CELL 2 CTG 1 VDD 3

GND 4

Battery Charger/System Voltage

PROG2 4

VREF_OUT 17

VSSA 16

GND$57 57 GND$58 58 GND$59 59 GND$60 60 GND$61 61

DSR$6 6

UBLOX_TXD UBLOX_RXD | | DCD$8 8
